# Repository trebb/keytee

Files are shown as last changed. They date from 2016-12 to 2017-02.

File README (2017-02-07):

keytee -- Controller breakout board for small keyboards

Keytee is based on the ATMEGA32U2 controller.  With its 20 usable I/O
pins, it can drive keyboards with up to 100 keys.  The PCB is intended
to sit between the switches of a mechanical keyboard, not adding any
bulk; cf. http://imgur.com/v3vOg1i.

./pcb/ contains the hardware design as a KiCAD project.

TMK-based ./firmware/ defines a 10-row, 10-column keymap with a total
of 10 keys that exercise all the hardware pins.  It is meant for
hardware testing and should probably adapted to any specific
requirements.

Generated bootloaders, firmware, Gerber files, etc. can be found at
https://trebb.github.io/keytee.

https://deskthority.net/workshop-f7/keytee-controller-breakout-board-for-small-keyboards-t15586.html

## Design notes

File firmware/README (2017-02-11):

In order to install a bootloader and to set the fuses, connect GND,
5V, RST, SCLK, MISO, and MOSI to a USBasp programmer; then,

$ make bootloader-dfu
$ make fuses

With the bootloader in place, plug the keytee USB terminal into your
computer.  You may have to initiate RESET by connecting RST to GND.
Then, build and upload firmware:

$ make dfu

Keymap, one key per column and row, for testing

 -----------
 key col row
 -----------
 0   B0  B1
 1   B2  B3
 2   B4  B5
 3   B6  B7
 
 4   C4  C5
 5   C6  C7
 
 6   D0  D1
 7   D2  D3
 8   D4  D5
 
 9   D6  C2
 ----------

 +--------+--------+--------------------------------------+--------+--------+
 | C6(C7) | C4(C5) |                                      | B6(B7) | B4(B5) |
 +--------+--------+                                      +--------+--------+
 | D+(D-) |                       front(back)                      | B2(B3) |
 +--------+--------+                                      +--------+--------+
 | 5V(GND)| C2(  ) |                                      | D6(RST)| B0(B1) |
 +--------+--------+-----------------                -----+--------+--------+
                                     \              /                     
                                     |              |                     
                                     |              |                     
                                     +----+----+----+                     
                                     |    |    |    |
                                     | D0 | D2 | D4 |                     
                                     |(D1)|(D3)|(D5)|
                                     |    |    |    |
                                     +----+----+----+

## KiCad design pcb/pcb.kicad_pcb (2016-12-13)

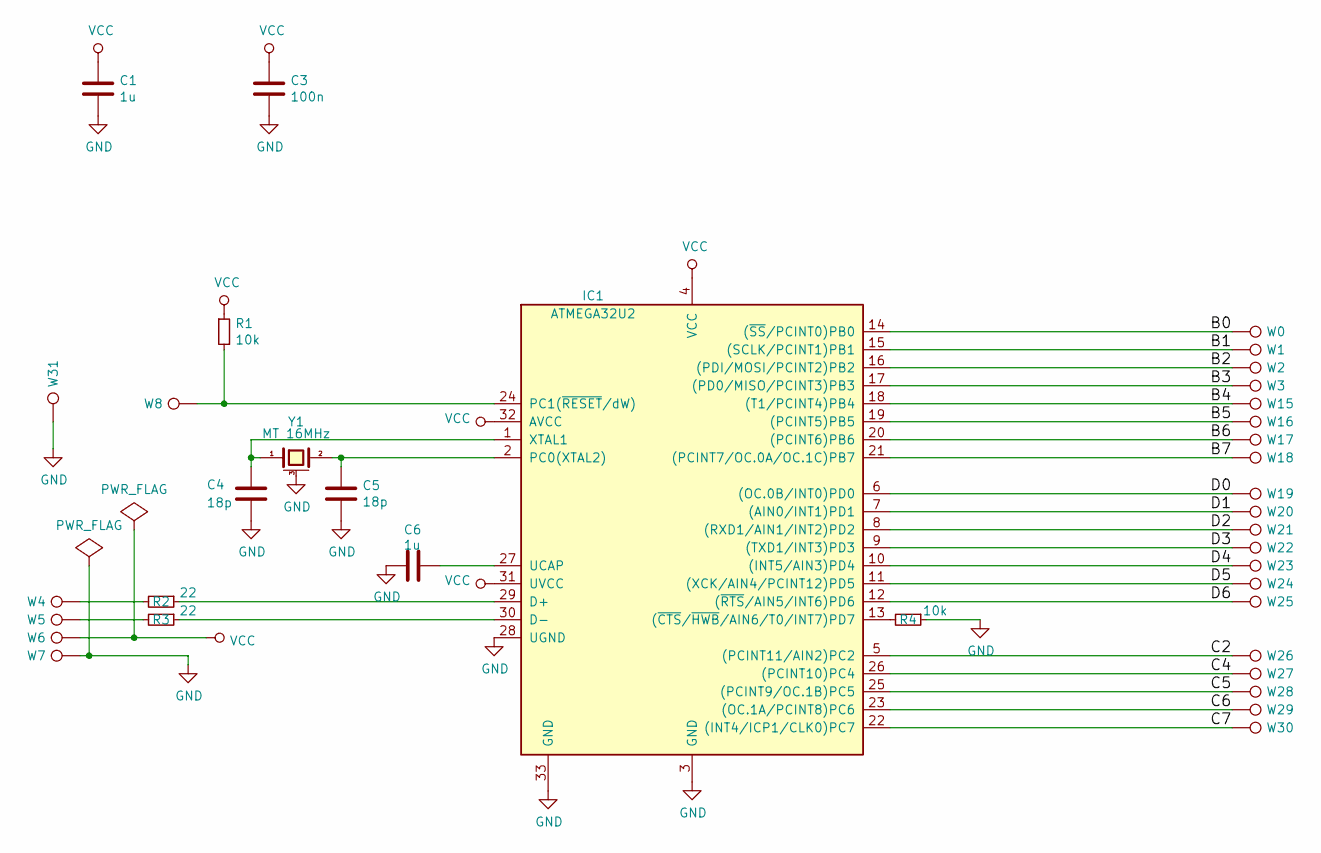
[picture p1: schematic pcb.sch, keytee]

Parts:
C1, C6: 1u; C_0402_square
C3: 100n; C_0402_square
C4, C5: 18p; C_0402_square
IC1: ATMEGA32U2; QFN-32-1EP_5x5mm_Pitch0.5mm_internal_vias
R1, R4: 10k; R_0402_square
R2, R3: 22; R_0402_square
W0, W1, W2, W3, W4, W5, W6, W7, W8, W15, W16, W17, W18, W19, W20, W21, W22, W23, W24, W25, W26, W27, W28, W29, W30: TEST_1P; SolderWirePad_SMD
W31: TEST_1P; SolderWirePad_SMD_circular
Y1: MT 16MHz; crystal_MT_32x25

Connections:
/B0: IC1.14 ((~SS~/PCINT0)PB0), W0.1
/B1: IC1.15 ((SCLK/PCINT1)PB1), W1.1
/B2: IC1.16 ((PDI/MOSI/PCINT2)PB2), W2.1
/B3: IC1.17 ((PD0/MISO/PCINT3)PB3), W3.1
/B4: IC1.18 ((T1/PCINT4)PB4), W15.1
/B5: IC1.19 ((PCINT5)PB5), W16.1
/B6: IC1.20 ((PCINT6)PB6), W17.1
/B7: IC1.21 ((PCINT7/OC.0A/OC.1C)PB7), W18.1
/C2: IC1.5 ((PCINT11/AIN2)PC2), W26.1
/C4: IC1.26 ((PCINT10)PC4), W27.1
/C5: IC1.25 ((PCINT9/OC.1B)PC5), W28.1
/C6: IC1.23 ((OC.1A/PCINT8)PC6), W29.1
/C7: IC1.22 ((INT4/ICP1/CLK0)PC7), W30.1
/D0: IC1.6 ((OC.0B/INT0)PD0), W19.1
/D1: IC1.7 ((AIN0/INT1)PD1), W20.1
/D2: IC1.8 ((RXD1/AIN1/INT2)PD2), W21.1
/D3: IC1.9 ((TXD1/INT3)PD3), W22.1
/D4: IC1.10 ((INT5/AIN3)PD4), W23.1
/D5: IC1.11 ((XCK/AIN4/PCINT12)PD5), W24.1
/D6: IC1.12 ((~RTS~/AIN5/INT6)PD6), W25.1
GND: C1.2, C3.2, C4.2, C5.2, C6.1, IC1.3 (GND), IC1.28 (UGND), IC1.33 (GND), R4.1, W7.1, W31.1, Y1.3 (case)
unnamed: C4.1, IC1.1 (XTAL1), Y1.1
unnamed: C5.1, IC1.2 (PC0(XTAL2)), Y1.2
unnamed: C6.2, IC1.27 (UCAP)
unnamed: IC1.13 ((~CTS~/~HWB~/AIN6/T0/INT7)PD7), R4.2
unnamed: IC1.24 (PC1(~RESET~/dW)), R1.2, W8.1
unnamed: IC1.29 (D+), R2.1
unnamed: IC1.30 (D-), R3.1
unnamed: R2.2, W4.1
unnamed: R3.2, W5.1
VCC: C1.1, C3.1, IC1.4 (VCC), IC1.31 (UVCC), IC1.32 (AVCC), R1.1, W6.1

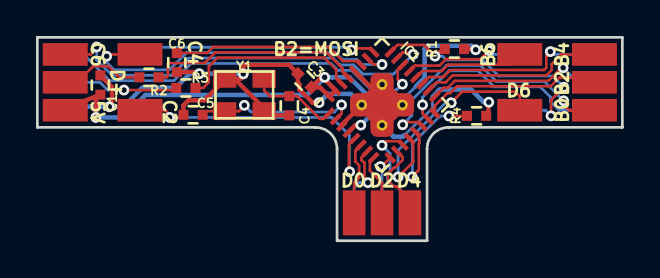
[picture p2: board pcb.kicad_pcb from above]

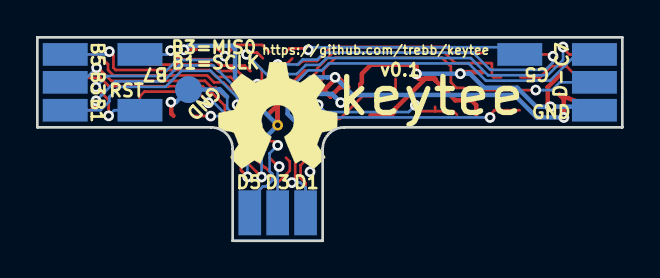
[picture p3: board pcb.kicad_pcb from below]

Board: 2 copper layers, 32.5 x 11.3 mm, 37 parts (13 on the bottom side), 31 nets.

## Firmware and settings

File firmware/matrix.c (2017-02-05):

/*
Copyright 2012 Jun Wako <wakojun@gmail.com>

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
You should have received a copy of the GNU General Public License
along with this program.  If not, see <http://www.gnu.org/licenses/>.
*/

/*
 * scan matrix
 */
#include <stdint.h>
#include <stdbool.h>
#include <avr/io.h>
#include <util/delay.h>
#include "print.h"
#include "debug.h"
#include "util.h"
#include "matrix.h"

#ifndef DEBOUNCE
#   define DEBOUNCE 5
#endif
static uint8_t debouncing = DEBOUNCE;

/* matrix state(1:on, 0:off) */
static matrix_row_t matrix[MATRIX_ROWS];
static matrix_row_t matrix_debouncing[MATRIX_ROWS];

static matrix_row_t read_cols(void);
static void init_cols(void);
static void unselect_rows(void);
static void select_row(uint8_t);

inline uint8_t
matrix_rows(void)
{
    return MATRIX_ROWS;
}

inline uint8_t
matrix_cols(void)
{
    return MATRIX_COLS;
}

void
matrix_init(void)
{
    // initialize row and col
    unselect_rows();
    init_cols();

    // initialize matrix state: all keys off
    for (uint8_t i=0; i < MATRIX_ROWS; i++) {
        matrix[i] = 0;
        matrix_debouncing[i] = 0;
    }
}

uint8_t
matrix_scan(void)
{
    for (uint8_t row = 0; row < MATRIX_ROWS; row++) {
        select_row(row);
        _delay_us(30);  // without this wait read unstable value.
        matrix_row_t cols = read_cols();
        if (matrix_debouncing[row] != cols) {
            matrix_debouncing[row] = cols;
            if (debouncing) {
                debug("bounce!: "); debug_hex(debouncing); debug("\n");
            }
            debouncing = DEBOUNCE;
        }
        unselect_rows();
    }

    if (debouncing) {
        if (--debouncing) {
            _delay_ms(1);
        } else {
            for (uint8_t i = 0; i < MATRIX_ROWS; i++) {
                matrix[i] = matrix_debouncing[i];
            }
        }
    }

    return 1;
}

bool
matrix_is_modified(void)
{
    if (debouncing) return false;
    return true;
}

inline bool
matrix_is_on(uint8_t row, uint8_t col)
{
    return (matrix[row] & ((matrix_row_t)1<<col));
}

inline matrix_row_t
matrix_get_row(uint8_t row)
{
    return matrix[row];
}

void
matrix_print(void)
{
    print("\nr/c 0123456789ABCDEF\n");
    for (uint8_t row = 0; row < MATRIX_ROWS; row++) {
        phex(row); print(": ");
        pbin_reverse16(matrix_get_row(row));
        print("\n");
    }
}

uint8_t
matrix_key_count(void)
{
    uint8_t count = 0;
    for (uint8_t i = 0; i < MATRIX_ROWS; i++) {
        count += bitpop16(matrix[i]);
    }
    return count;
}

/* Column pin configuration
 * col: 0  1  2  3  4  5  6  7  8  9
 * pin: B0 B2 B4 B6 C4 C6 D0 D2 D4 D6
 */
static void
init_cols(void)
{
    // Input with pull-up(DDR:0, PORT:1)
    DDRB  &= ~0b01010101;
    PORTB |=  0b01010101;
    DDRC  &= ~0b01010000;
    PORTC |=  0b01010000;
    DDRD  &= ~0b01010101;
    PORTD |=  0b01010101;
}

static matrix_row_t
read_cols(void)
{
    return
        (PINB&(1<<0) ? 0 : (1<<0)) |
        (PINB&(1<<2) ? 0 : (1<<1)) |
        (PINB&(1<<4) ? 0 : (1<<2)) |
        (PINB&(1<<6) ? 0 : (1<<3)) |
        (PINC&(1<<4) ? 0 : (1<<4)) |
        (PINC&(1<<6) ? 0 : (1<<5)) |
        (PIND&(1<<0) ? 0 : (1<<6)) |
        (PIND&(1<<2) ? 0 : (1<<7)) |
        (PIND&(1<<4) ? 0 : (1<<8)) |
        (PIND&(1<<6) ? 0 : (1<<9));
}

/* Row pin configuration
 * col: 0  1  2  3  4  5  6  7  8  9
 * pin: B1 B3 B5 B7 C5 C7 D1 D3 D5 C2
 */
static void
unselect_rows(void)
{
    // Hi-Z(DDR:0, PORT:0) to unselect
    DDRB  &= ~0b10101010;
    PORTB &= ~0b10101010;
    DDRC  &= ~0b10100100;
    PORTC &= ~0b10100100;
    DDRD  &= ~0b00101010;
    PORTD &= ~0b00101010;
}

static void
select_row(uint8_t row)
{
    // Output low(DDR:1, PORT:0) to select
    switch (row) {
    case 0:
        DDRB  |=  (1<<1);
        PORTB &= ~(1<<1);
        break;
    case 1:
        DDRB  |=  (1<<3);
        PORTB &= ~(1<<3);
        break;
    case 2:
        DDRB  |=  (1<<5);
        PORTB &= ~(1<<5);
        break;
    case 3:
        DDRB  |=  (1<<7);
        PORTB &= ~(1<<7);
        break;
    case 4:
        DDRC  |=  (1<<5);
        PORTC &= ~(1<<5);
        break;
    case 5:
        DDRC  |=  (1<<7);
        PORTC &= ~(1<<7);
        break;
    case 6:
        DDRD  |=  (1<<1);
        PORTD &= ~(1<<1);
        break;
    case 7:
        DDRD  |=  (1<<3);
        PORTD &= ~(1<<3);
        break;
    case 8:
        DDRD  |=  (1<<5);
        PORTD &= ~(1<<5);
        break;
    case 9:
        DDRC  |=  (1<<2);
        PORTC &= ~(1<<2);
        break;
    }
}

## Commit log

2016-12-07 Tweak USB tracks to resemble a differential pair
    [pcb.kicad_pcb]
2016-12-13 Adapt to manufacturer's capabilities
    [pcb.kicad_pcb]
2017-02-05 Fix firmware including bootloader
    We now have a minimal testing keymap.
    [matrix.c]
2017-02-09 keytee has its own USB PID, issued by http://pid.codes: 0xE4EE

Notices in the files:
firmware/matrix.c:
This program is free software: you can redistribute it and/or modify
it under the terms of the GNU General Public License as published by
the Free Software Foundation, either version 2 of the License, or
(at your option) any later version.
